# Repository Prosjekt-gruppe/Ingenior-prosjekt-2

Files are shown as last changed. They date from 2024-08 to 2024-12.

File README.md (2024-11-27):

# Ingenior-prosjekt-2

Velkommen til Gruppe 1 sitt prosjekt. Her finner du problemstillingen og andre nyttinge linker til resusser.

# Problemstilling

Vi har fått i oppgave med å gi blinde og synshemmede hjelp med å oppfatte omverden.

# Timeline
|Hvem|Når|
|-|-|
|Prototype 2|10.Okt-18.Nov|
|Dokumentering|18.Nov - 1.Des|
|Innlevering av prosjekt|Kl 12:00 6.Desember|

# ESP32-S3 Pinout


# Ansvarsområder
|Hvem|Hva|
|-|-|
|Ottar Rolfsrud|3D design/HW dokumentasjon|
|Olav André Telneset|Skyløsning|
|He You Ma|NFC avlesning|
|Yamn Sultan Salim|Sko programmering|

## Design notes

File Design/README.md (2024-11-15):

# Arkitektur



## Deler
|Del|Bruk|Antall|
|:---:|:-----:|:-----:|
|TPU|3D print fillament||

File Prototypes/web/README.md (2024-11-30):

# TODO:
- [x] Setup server
- [x] Setup DNS
- [x] Get domain name
- [x] Setup firewall
- [x] Secure site with SSL
- [x] Setup general flask layout
- [x] Configure nginx as reverse proxy
- [x] Setup service for gunicorn
- [x] Setup basic mqtt over websocket
- [x] Protect mqtt implementation with username
- [x] Websocket support
- [x] MQTT-device receiving input-values
- [x] Favicon
- [ ] Protect mqtt messages with ssl
- [x] Setup API for devices
- [x] Setup db
- [x] Integrate mazemap
- [x] Cookies
- [x] Make site nicer
- [x] Implement audio response

# For next prototype:
Expand multi-user functionality and improve security. Also cleanup of code and improve loggin-implementation.

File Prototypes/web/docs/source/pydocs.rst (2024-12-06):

Python
========

Kildekode for Flask-appen og MQTT-klienten.

Flask-app
---------
`app/audiostream.py`

.. literalinclude:: ../../app/audiostream.py
   :language: python
   :linenos:

`app/front.py`

.. literalinclude:: ../../app/front.py
   :language: python
   :linenos:

`app/landing.py`

.. literalinclude:: ../../app/landing.py
   :language: python
   :linenos:

`app/mqtt.py`

.. literalinclude:: ../../app/mqtt.py
   :language: python
   :linenos:

`app/sockets.py`

.. literalinclude:: ../../app/sockets.py
   :language: python
   :linenos:

Python MQTT-klient
------------------

`mqttclient/mqttservice.py`

.. literalinclude:: ../../mqttclient/mqttservice.py
   :language: python
   :linenos:

JavaScript
===========

Befinner seg i mappen `app/static/js`

`script.js`

.. literalinclude:: ../../app/static/js/script.js
   :language: javascript
   :linenos:

`mmap.js`

.. literalinclude:: ../../app/static/js/mmap.js
   :language: javascript
   :linenos:

`audio.js`

.. literalinclude:: ../../app/static/js/audio.js
   :language: javascript
   :linenos:

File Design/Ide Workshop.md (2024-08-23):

# Ide workshop

## Ide 1

- En klokke som guider den blinde frem til “airtags” og hvor man kan snu på et ut for å velge hvor man skal. Guidingen skal skje via minst 4 vibrasjons punkter som anngir 8 rettninger for at brukeren skal presist nå frem til målet.
    - Ha piping på “airtagene” for enklere lokalisering
    - Benytte et ut på klokken som velger mål som den blinde skal guides til
- Test 1
    - Testet med telefon lyd og evt vibrasjon for å teste ideen. Testen bestod av en tester med med bind for øyene, de skal finne riktig telefon som lager lyd på et litt rotete bord.
    - Testerene brukte variert tid på å finne frem til telefonen med lyden, men de fant telefonen iløpet av 3 minutt.

## Ide 2

### Problemstilling

Hvordan kan vi hjelpe blinde/svaksynte få en bedre oversikt om omgivelsene? Mer spesifikt; hvordan kan vi hjelpe dem unngå diverse uventede hindringer på en intuitiv og bekvemmelig måte. Hvordan gjør vi at løsningen bidrar til brukerens generelle orienteringsevne.

### Løsning

- Sko med et sensor array, hvor man kan kjenne avstand til vegger, folk og hindringer ved vibrasjonsstyrke. Dette skal skje ved bruk av avstandssensorere som reagerer på avstander som er mer enn armlengden til brukeren.
- Skoen skal også være utstyrt med en nfc leser som gir brukeren informasjon om plasseringen du oppholder deg på.

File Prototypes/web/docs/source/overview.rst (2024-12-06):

Systemoversikt
===============

Løsningen er implementert i henhold til figuren:

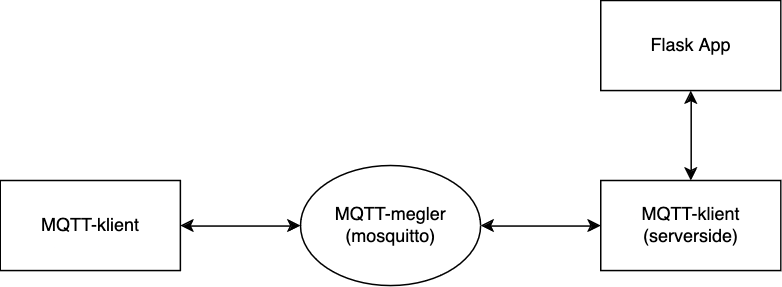
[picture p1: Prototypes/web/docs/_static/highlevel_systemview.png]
Overordnet systemoversikt


   Overblikk av MQTT-systemet.

Her ser vi et overblikk over hvordan MQTT kommunikasjonen er implementert.

Detaljert beskrivelse
----------------

Nednefor kan man observere i større grad hvordan de forskjellige delene
av systemet henger sammen.

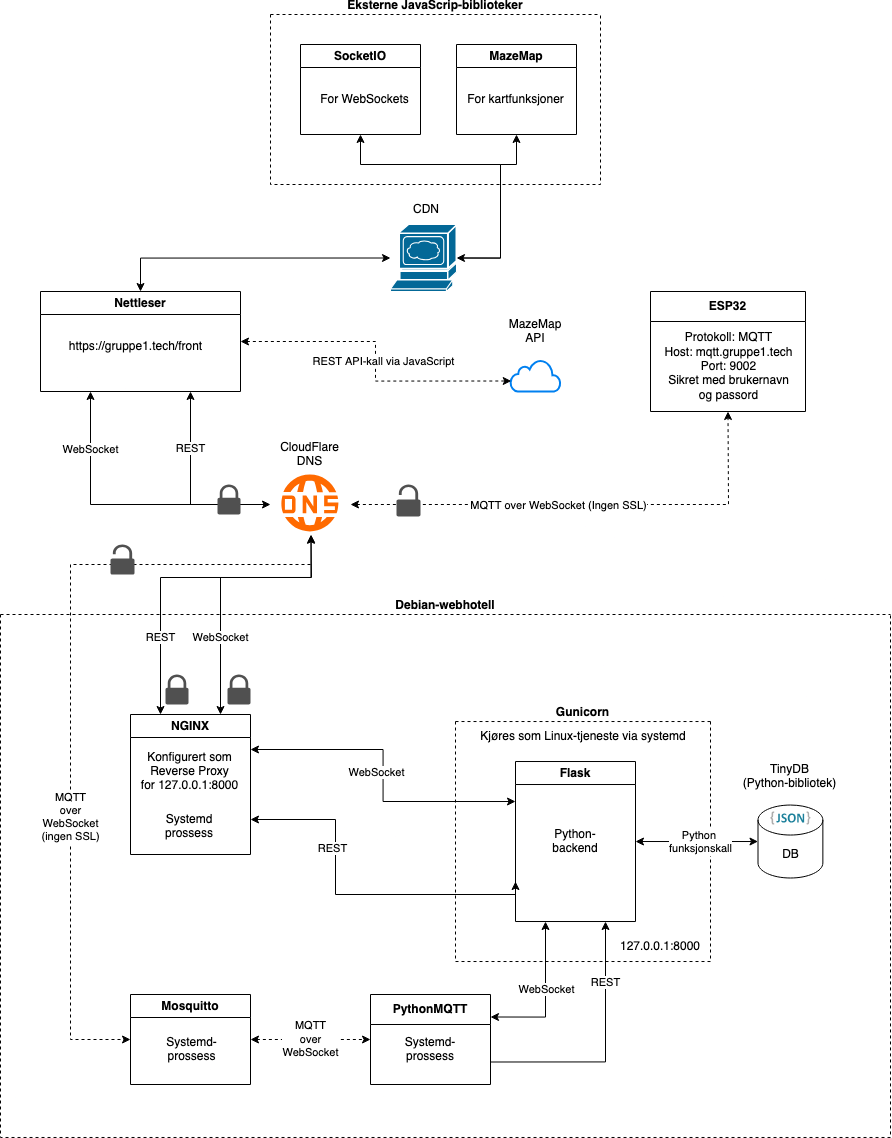
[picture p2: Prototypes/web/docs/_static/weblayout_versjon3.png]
Detaljert systemoversikt


   Detaljert overblikk av WebServeren.

Flask-app
----------

Python-biblioteket Flask ble brukt som rammeverk for å sette opp nettsiden. 
Denne løsningen egner seg godt til prototyping da det tillater rask utvikling av nettsider. 
Se `flask.palletsprojects.com <https://flask.palletsprojects.com/en/stable/>`_ for mer informasjon.
Hver modul er definert i sin egen python-fil i app-mappen.

.. toctree::
   :maxdepth: 2

   modules

MQTT
-----
.. toctree::
   :maxdepth: 1

   mqttclient

Omvendt proxy (NGINX)
----------------------
.. toctree::
   :maxdepth: 2

   nginx

Systemd
--------
.. toctree::
   :maxdepth: 2

   services

Byggskript
-----------

.. toctree::
   :maxdepth: 2

   build

Avhengigheter
-------------

.. toctree::
   :maxdepth: 2

   dependencies

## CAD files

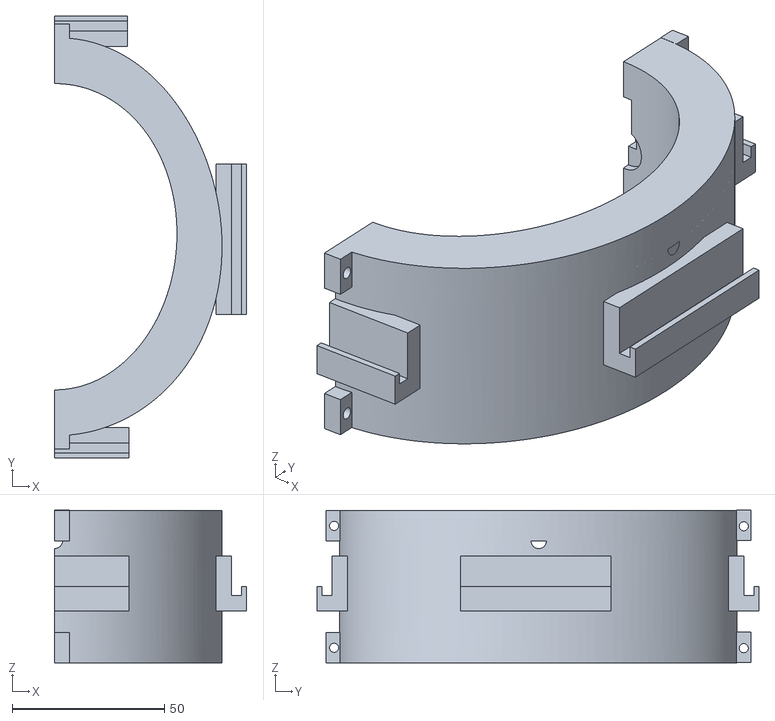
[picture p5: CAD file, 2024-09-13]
Design/3D Design/Blind Sko.V1.stl
63.0 x 145.0 x 50.1

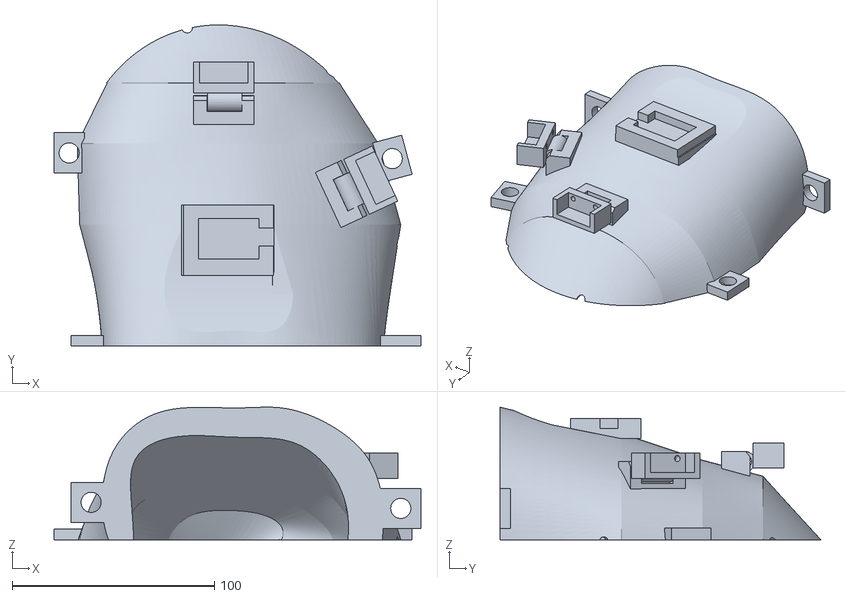
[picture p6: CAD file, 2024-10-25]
Design/3D Design/Blind Sko.V2/Sko top frem.stl
181.3 x 158.7 x 65.6

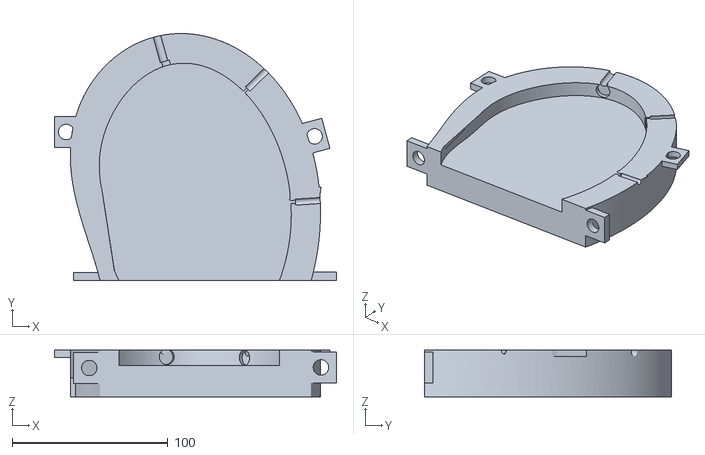
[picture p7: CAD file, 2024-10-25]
Design/3D Design/Blind Sko.V2/Sko frem såle.stl
181.2 x 158.7 x 30.0

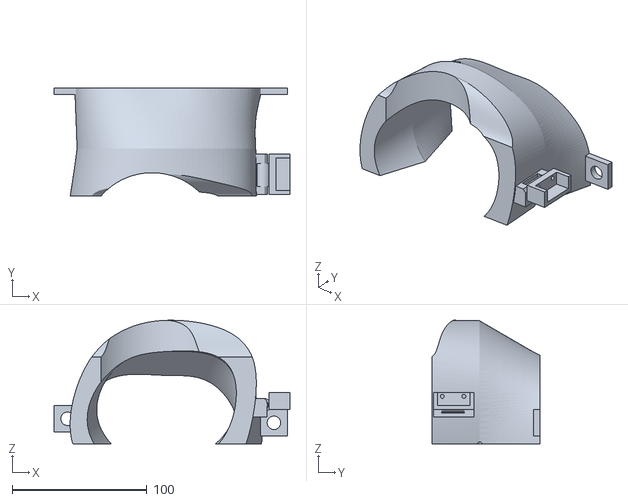
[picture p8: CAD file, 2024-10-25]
Design/3D Design/Blind Sko.V2/Sko top mid.stl
174.9 x 80.0 x 91.6

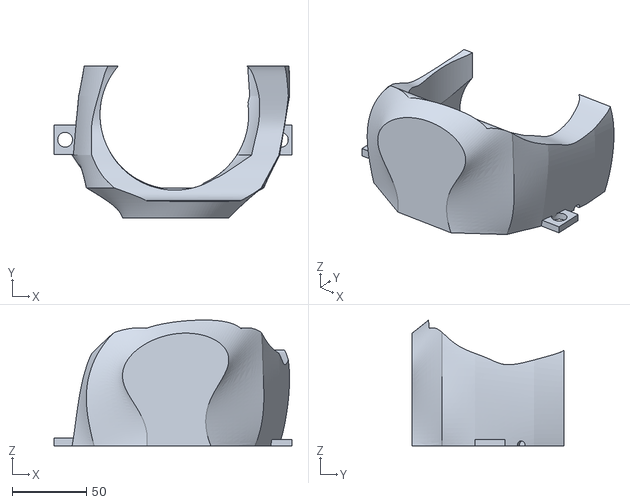
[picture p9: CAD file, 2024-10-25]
Design/3D Design/Blind Sko.V2/Sko top bak.stl
160.2 x 102.2 x 84.8

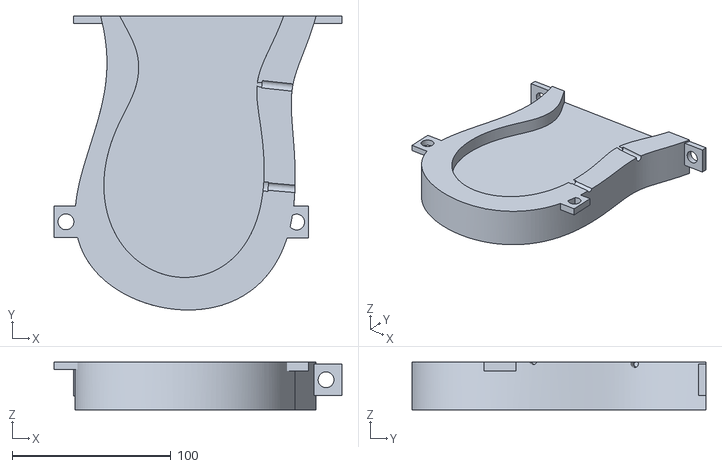
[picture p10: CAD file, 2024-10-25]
Design/3D Design/Blind Sko.V2/Sko såle bak.stl
181.2 x 185.1 x 30.0

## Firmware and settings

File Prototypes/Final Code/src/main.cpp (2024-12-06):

// Include the necessary libraries
#include <Arduino.h>
#include <WiFi.h>
#include <SPI.h>
#include <WebSocketsClient.h>
#include <MQTTPubSubClient.h>
#include <MFRC522.h>
#include <VL53L0X.h>

// Macro definitions for string conversion
#define XSTR(x) #x
#define STR(x) XSTR(x)

// MQTT Configuration (DON'T LEAK THIS TO GITHUB!!!)
const char* MQTT_HOSTNAME = "mqtt.gruppe1.tech"; //Define the MQTT broker address
const char* MQTT_TOPIC = "devices/1/location"; // Define the topic to publish to
const int MQTT_PORT1 = 9002; // Define the port to connect to
const char* MQTT_PASSWORD = STR(MQTT_PASSWD); //The password is defined in a local file
const char* MQTT_USER = STR(MQTT_USERNAME); //The username is defined in a local file

// Wi-Fi Configuration (DON'T LEAK THIS TO GITHUB!!!)
const char* ssid = "";
const char* pass = "";

WebSocketsClient client;
MQTTPubSubClient mqtt;

// Set up the pins for the RFID reader
#define RST_PIN         1
#define SS_PIN          9
#define MOSI_PIN        2
#define MISO_PIN        11
#define SCK_PIN         10
#define BUZZER_PIN      5

// Set up the pins for the distance sensors
#define SDA_PIN 13
#define SCL_PIN 12
#define XSHUT_PIN_1 4
#define XSHUT_PIN_2 6
#define XSHUT_PIN_3 7
const unsigned int mindistance = 50;
const unsigned int maxdistance = 300;

//Define pins for the PWM control
const unsigned int freq = 20000;
const unsigned int ledChannel0 = 0; // PWM channel for motor 1
const unsigned int ledChannel1 = 1; // PWM channel for motor 2
const unsigned int ledChannel2 = 2; // PWM channel for motor 3
const unsigned int resolution = 8;
const unsigned int maxDutyCycle = 255;
float dutyCycleMotor1 = 0;
float dutyCycleMotor2 = 0;
float dutyCycleMotor3 = 0;
float dutyCycleIntervals = maxDutyCycle / (maxdistance - mindistance);

// Define pins for the motors
const int motor1 = 3;
const int motor2 = 8;
const int motor3 = 14;

// Create VL53L0X sensor instances
VL53L0X sensor1;
VL53L0X sensor2;
VL53L0X sensor3;

// Create MFRC522 instance
MFRC522 mfrc522(SS_PIN, RST_PIN);

// Function to handle Wi-Fi and MQTT connections
void connect() {
connect_to_wifi:
    Serial.print("connecting to wifi...");
    while (WiFi.status() != WL_CONNECTED) {
        Serial.print(".");
        delay(1000);
    }
    Serial.println(" connected!");

connect_to_host:
    Serial.println("connecting to host...");
    client.disconnect();
    client.begin(MQTT_HOSTNAME, MQTT_PORT1, "/", "mqtt");  // "mqtt" is required
    client.setReconnectInterval(2000);

    Serial.print("connecting to mqtt broker...");
    while (!mqtt.connect("esp32-client", MQTT_USER, MQTT_PASSWORD)) {
        Serial.print(".");
        delay(1000);
        if (WiFi.status() != WL_CONNECTED) {
            Serial.println("WiFi disconnected");
            goto connect_to_wifi;
        }
        if (!client.isConnected()) {
            Serial.println("WebSocketsClient disconnected");
            goto connect_to_host;
        }
    }
    Serial.println(" connected!");
}

void setup() {
    //Initialize the motor to set it off
    pinMode(motor1, OUTPUT);
    digitalWrite(motor1, LOW);
    pinMode(motor2, OUTPUT);
    digitalWrite(motor2, LOW);
    pinMode(motor3, OUTPUT);
    digitalWrite(motor3, LOW);

    // Play startup sound (Family Mart jingle)
    pinMode(BUZZER_PIN, OUTPUT);
    tone(BUZZER_PIN, 740, 400);
    tone(BUZZER_PIN, 587, 400);
    tone(BUZZER_PIN, 440, 400);
    tone(BUZZER_PIN, 587, 400);
    tone(BUZZER_PIN, 659, 400);
    tone(BUZZER_PIN, 880, 800);
    tone(BUZZER_PIN, 659, 400);
    tone(BUZZER_PIN, 740, 400);
    tone(BUZZER_PIN, 659, 400);
    tone(BUZZER_PIN, 440, 400);
    tone(BUZZER_PIN, 587, 800);


    Wire.begin(SDA_PIN, SCL_PIN);  // Initialize I2C bus
    Serial.begin(115200);

    // Initialize XSHUT pins
    pinMode(XSHUT_PIN_1, OUTPUT);
    pinMode(XSHUT_PIN_2, OUTPUT);
    pinMode(XSHUT_PIN_3, OUTPUT);

    // Shutdown all sensors
    digitalWrite(XSHUT_PIN_1, LOW);
    digitalWrite(XSHUT_PIN_2, LOW);
    digitalWrite(XSHUT_PIN_3, LOW);
    delay(10);  // Short delay to ensure sensors are in shutdown

    // Initialize and assign new address to sensor 1
    digitalWrite(XSHUT_PIN_1, HIGH);
    delay(10);  // Wait for the sensor to boot up
    sensor1.setAddress(0x30);  // New I2C address for sensor 1
    sensor1.init();
    sensor1.startContinuous();

    // Initialize and assign new address to sensor 2
    digitalWrite(XSHUT_PIN_2, HIGH);
    delay(10);  // Wait for the sensor to boot up
    sensor2.setAddress(0x31);  // New I2C address for sensor 2
    sensor2.init();
    sensor2.startContinuous();

    // Initialize and assign new address to sensor 3
    digitalWrite(XSHUT_PIN_3, HIGH);
    delay(10);  // Wait for the sensor to boot up
    sensor3.setAddress(0x32);  // New I2C address for sensor 3
    sensor3.init();
    sensor3.startContinuous();
    
    delay(5000); // Wait before activating the motors, or else there will be failures

    // Initialize PWM channels
    ledcSetup(ledChannel0, freq, resolution);
    ledcSetup(ledChannel1, freq, resolution);
    ledcSetup(ledChannel2, freq, resolution);

    //Attach motor to PWM channel
    ledcAttachPin(motor1, ledChannel0);
    ledcAttachPin(motor2, ledChannel1);
    ledcAttachPin(motor3, ledChannel2);

    //Ensure that the motors are off
    ledcWrite(ledChannel0, 0);
    ledcWrite(ledChannel1, 0);
    ledcWrite(ledChannel2, 0);

    
    // Begin Wi-Fi connection
    WiFi.begin(ssid, pass);

    // Initialize SPI bus
    SPI.begin(SCK_PIN, MISO_PIN, MOSI_PIN, SS_PIN);

    // Initialize MFRC522 RFID reader
    mfrc522.PCD_Init();

    // Initialize MQTT client
    mqtt.begin(client);

    // Connect to Wi-Fi, host, and MQTT broker
    connect();


}

unsigned long TOFMillis = 0;
const unsigned long TOFInterval = 100;
const uint32_t cardReadInterval = 1000; // Interval in milliseconds

void loop() {
    // Update MQTT client regularly
    mqtt.update();

    unsigned long currentMillis = millis();

    // Non-blocking delay for card reading
    static uint32_t lastCardReadTime = 0;

    // Check if it's time to read the card again
    if (currentMillis - lastCardReadTime >= cardReadInterval) {
        // Try to read the card
        if (mfrc522.PICC_IsNewCardPresent() && mfrc522.PICC_ReadCardSerial()) {
            Serial.println(F("\n**Start Reading**"));
            lastCardReadTime = currentMillis;

            // Card detected
            Serial.println(F("**Card Detected:**"));

            // Dump details about the card
            mfrc522.PICC_DumpDetailsToSerial(&(mfrc522.uid));

            // Setup a string to hold the UID of the card
            String uidString = "";

            // Print Card UID and build string
            Serial.print(F("Card UID:"));
            for (byte i = 0; i < mfrc522.uid.size; i++) {
                // Print each byte to the serial monitor
                Serial.print(mfrc522.uid.uidByte[i] < 0x10 ? " 0" : " ");
                Serial.print(mfrc522.uid.uidByte[i], HEX);

                // Add each byte to the string
                if (mfrc522.uid.uidByte[i] < 0x10) {
                    uidString += "0";
                }
                uidString += String(mfrc522.uid.uidByte[i], HEX);
            }
            Serial.println();

            // Convert the UID to uppercase
            uidString.toUpperCase();

            // Now you can use uidString as needed
            // For example, publish it via MQTT
            mqtt.publish(MQTT_TOPIC, uidString);

            Serial.println(F("\n**End Reading**\n"));

            // Halt PICC and stop encryption on PCD
            mfrc522.PICC_HaltA();
            mfrc522.PCD_StopCrypto1();
        }
        // No else needed; if no card is present, simply continue
    }

    // Sensor reading code
    if (currentMillis - TOFMillis >= TOFInterval) {
        TOFMillis = currentMillis;

        // Read from sensor 1
        uint16_t distance1 = sensor1.readRangeContinuousMillimeters();
        if (sensor1.timeoutOccurred()) {
            Serial.println("Sensor 1 timeout!");
        } else {
            Serial.print("Distance 1: ");
            Serial.print(distance1);
            Serial.println(" mm");
            if (distance1 < maxdistance && distance1 > mindistance) {
                dutyCycleMotor1 = (maxdistance - distance1) * dutyCycleIntervals;
                int integerDutyCycleMotor1 = (int)dutyCycleMotor1;
                ledcWrite(ledChannel0, integerDutyCycleMotor1);
            } else {
                ledcWrite(ledChannel0, 0);
            }
        }

        // Read from sensor 2
        uint16_t distance2 = sensor2.readRangeContinuousMillimeters();
        if (sensor2.timeoutOccurred()) {
            Serial.println("Sensor 2 timeout!");
        } else {
            Serial.print("Distance 2: ");
            Serial.print(distance2);
            Serial.println(" mm");
            if (distance2 < maxdistance && distance2 > mindistance) {
                dutyCycleMotor2 = (maxdistance - distance2) * dutyCycleIntervals;
                int integerDutyCycleMotor2 = (int)dutyCycleMotor2;
                ledcWrite(ledChannel1, integerDutyCycleMotor2);
            } else {
                ledcWrite(ledChannel1, 0);
            }
        }

        // Read from sensor 3
        uint16_t distance3 = sensor3.readRangeContinuousMillimeters();
        if (sensor3.timeoutOccurred()) {
            Serial.println("Sensor 3 timeout!");
        } else {
            Serial.print("Distance 3: ");
            Serial.print(distance3);
            Serial.println(" mm");
            if (distance3 < maxdistance && distance3 > mindistance) {
                dutyCycleMotor3 = (maxdistance - distance3) * dutyCycleIntervals;
                int integerDutyCycleMotor3 = (int)dutyCycleMotor3;
                ledcWrite(ledChannel2, integerDutyCycleMotor3);
            } else {
                ledcWrite(ledChannel2, 0);
            }
        }
    }
}

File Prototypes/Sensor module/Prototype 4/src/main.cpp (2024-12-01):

#include <Adafruit_VL53L0X.h>
#include <Wire.h>


/*----------------------------*/
/*------Distance Sensors------*/
/*----------------------------*/

// Distance Sensor setup
Adafruit_VL53L0X lox1 = Adafruit_VL53L0X(); // Working
Adafruit_VL53L0X lox2 = Adafruit_VL53L0X(); // Not Checked
Adafruit_VL53L0X lox3 = Adafruit_VL53L0X(); // Not Checked

// Distance Sensor 1 (SDA: 8, SCL: 9)
const int loxSDA1 = 8;   
const int loxSCL1 = 9;   

// Distance Sensor 2 (SDA: 10, SCL: 11)
const int loxSDA2 = 10;   
const int loxSCL2 = 11;   

// Distance Sensor 3 (SDA: 12, SCL: 13)
const int loxSDA3 = 12;   
const int loxSCL3 = 13;   


// Initialization of distance sensor
void loxSetup() {

  // Initialize sensor 1
  Wire.begin(loxSDA1, loxSCL1);
  if (!lox1.begin()) {
    Serial.println("Could not initialize VL53L0X sensor 1");
    while (1);
  }
  Serial.println("Sensor 1 initialized");


  // Initialize sensor 2
  Wire.begin(loxSDA2, loxSCL2);
  if (!lox2.begin()) {
    Serial.println("Could not initialize VL53L0X sensor 2");
    while (1);
  }
  Serial.println("Sensor 2 initialized");


  // Initialize sensor 3
  Wire.begin(loxSDA3, loxSCL3);
  if (!lox3.begin()) {
    Serial.println("Could not initialize VL53L0X sensor 3");
    while (1);
  }
  Serial.println("Sensor 3 initialized");
}




// Vibration Motor setup
const int vibPin0 = 3;  // GPIO for Vibration motor 1 (PWM) Testing 
const int vibPin1 = 4;  // GPIO for Vibration motor 2 (PWM)
const int vibPin2 = 5;  // GPIO for Vibration motor 3 (PWM)
const int vibPin3 = 6;  // GPIO for Vibration motor 4 (PWM)
const int vibPin4 = 7;  // GPIO for Vibration motor 5 (PWM)


// Function to activate vibration motor if distance is below 300mm
// Parameters:
// - distanceSensor: the sensor object to take measurements from
// - vibPin: the vibration pin to control the motor
// - intensityCoeff: the intensity multiplier (1-10) to adjust vibration feedback

void controlVibration(Adafruit_VL53L0X& distanceSensor, int vibPin, int intensityCoeff, bool debugMode) {
  VL53L0X_RangingMeasurementData_t measure;
  
  // Measure the distance
  distanceSensor.rangingTest(&measure, false);

  // Check if the measurement is valid
  if (measure.RangeStatus != 4) { // 4 indicates an invalid measurement
    int distance = measure.RangeMilliMeter;
    // Print distance values for debugging if debugMode is true
    if (debugMode) {
      Serial.print("Distance (mm): ");
      Serial.println(distance);
    }

    // Trigger vibration motor if distance is below 300 mm
    if (distance < 300) {
      // Adjust intensity using a multiplier (intensityCoeff)
      // The map range is modified to give a range between 0 and 255 (PWM)
      int intensity = map(distance, 0, 300, 255, 0); // Map distance to PWM value
      intensity = intensity * intensityCoeff; // Apply intensity coefficient

      // Ensure intensity stays within valid PWM range (0 to 255)
      if (intensity > 255) intensity = 255;
      if (intensity < 0) intensity = 0;


      Serial.println("Inensity:");
      Serial.println(intensity);

      analogWrite(vibPin, intensity);  // Set the motor vibration intensity for the selected motor pin
    } else {
      analogWrite(vibPin, 0); // Turn off the motor if distance is above 300mm
    }
  } else {
    if (debugMode) {
      Serial.println("Out of reach");
    }
    analogWrite(vibPin, 0); // Ensure motor is off if measurement is out of range
  }
}

void setup() {
  Serial.begin(115200);
  // Setup distance sensors
  loxSetup();

}

void loop() {
  // Call the controlVibration function with appropriate parameters:

  // First sensor controls vibPin0 and vibPin1 
  controlVibration(lox1, vibPin0, 1, false);  // Debug mode enabled

  /*
  // Second sensor controls vibPin0 and vibPin1 
  controlVibration(lox2, vibPin3, 5, false);  // Debug mode enabled

  // Third sensor controls vibPin0 and vibPin1 
  controlVibration(lox3, vibPin4, 5, true);  // Debug mode enabled

  */


  delay(50);  // Delay to avoid flooding the serial monitor
}

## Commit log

2024-09-13 legger til protype 3d-print-fil av Ottar
    [Blind-Sko.v1 v12.stl]
2024-10-03 La til 3D model i riktig folder
    [Blind Sko.v1 v12.stl]
2024-10-03 Rename Design/Blind Sko.v1 v12.stl to Design/3D Design/Blind Sko.v1 v12.stl
    [Blind Sko.v1 v12.stl]
2024-10-03 Rename Blind Sko.v1 v12.stl to Blind Sko.V1.stl
    [Blind Sko.V1.stl]
2024-10-25 Versjon 2 av Blind sko 3D model
    [Sko frem såle.stl, Sko såle bak.stl, Sko top bak.stl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]
2024-10-25 Flyttet til riktig plass
    [Sko frem såle.stl, Sko såle bak.stl, Sko top bak.stl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]
2024-10-31 Update README.md
    Nytt ESP32 bilde
2024-11-01 Lagt til kode for I2C varifisering og Distance avlesning mva VL53L0X sensor
2024-11-05 Sensor_module Prototype 2
2024-11-05 Sensor_module: Prototype 3 Endringe gjort: Lagt til modul for øke intensitet i vibrasjon, minking av distanse målinger
2024-11-06 Make devices recognizable
2024-11-08 Setup MQTT for esp32
2024-11-08 Make sure socketio loads correctly in browser
2024-11-24 Use socket.io websockets
2024-11-25 Web schematic
2024-11-27 Debug sockets
2024-11-27 Restructure sockets
2024-11-27 Restructure sockets more
2024-11-27 Try fixing sockets
2024-11-27 Better socket handling
2024-11-27 Update button
2024-11-27 Fix button
2024-11-27 Set device
2024-11-27 Make static button
2024-11-28 Removed delay and added millis
2024-11-28 Adding circut drawing to design folder
    [Blind-Sko.v1 v12.stl]
2024-11-28 Prototype 3: WiFi- connection & Subscribe to MQTT + messages reader
2024-11-30 Make sure message returns to selected device
2024-12-01 Prototype 4
2024-12-04 Use this to grab your I2C address
2024-12-04 Starting on motor functions
2024-12-04 More motor work
2024-12-05 Prototype 1: Initializing single sensor & I2C scanner
2024-12-05 Prototype 1: Initialize sensor 1 & Reading Distance
2024-12-05 Prototype 2: Added second VL53L0X sensor & measuring distance of both sensors
2024-12-05 Added vibration motor functions
    [main.cpp]
2024-12-05 Added wire to main.cpp
2024-12-05 Reverting back to no motor
    [main.cpp]
2024-12-06 One motor is working perfectly
2024-12-06 Finished code for 3 motors, more can still be added
